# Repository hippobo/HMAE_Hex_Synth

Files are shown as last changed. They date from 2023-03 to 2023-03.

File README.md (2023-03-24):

# HMAE_Hex_Synth

Hex Synth project with resistive touch pads based on ekkoflok hex synth project : https://www.ekkoflok.dk/hex.php

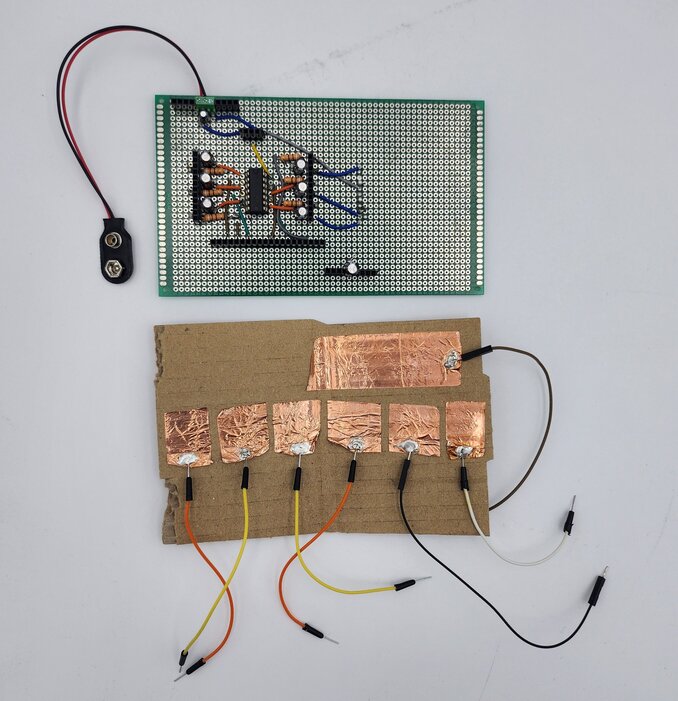
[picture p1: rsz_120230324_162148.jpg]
Prototype

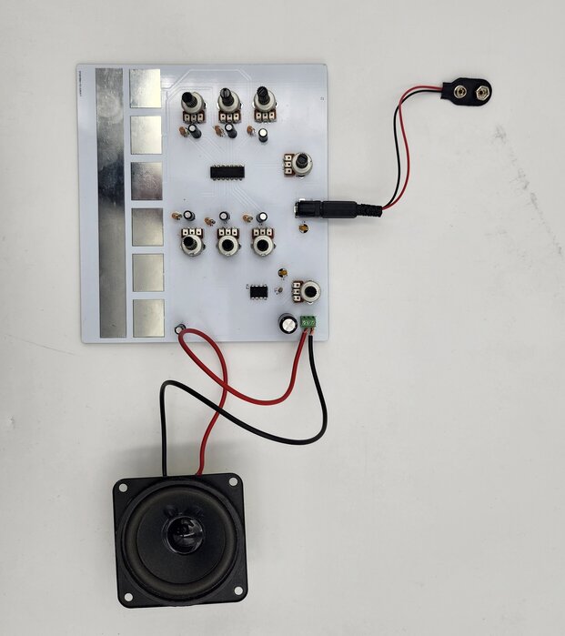
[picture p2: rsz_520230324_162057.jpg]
Final PCB


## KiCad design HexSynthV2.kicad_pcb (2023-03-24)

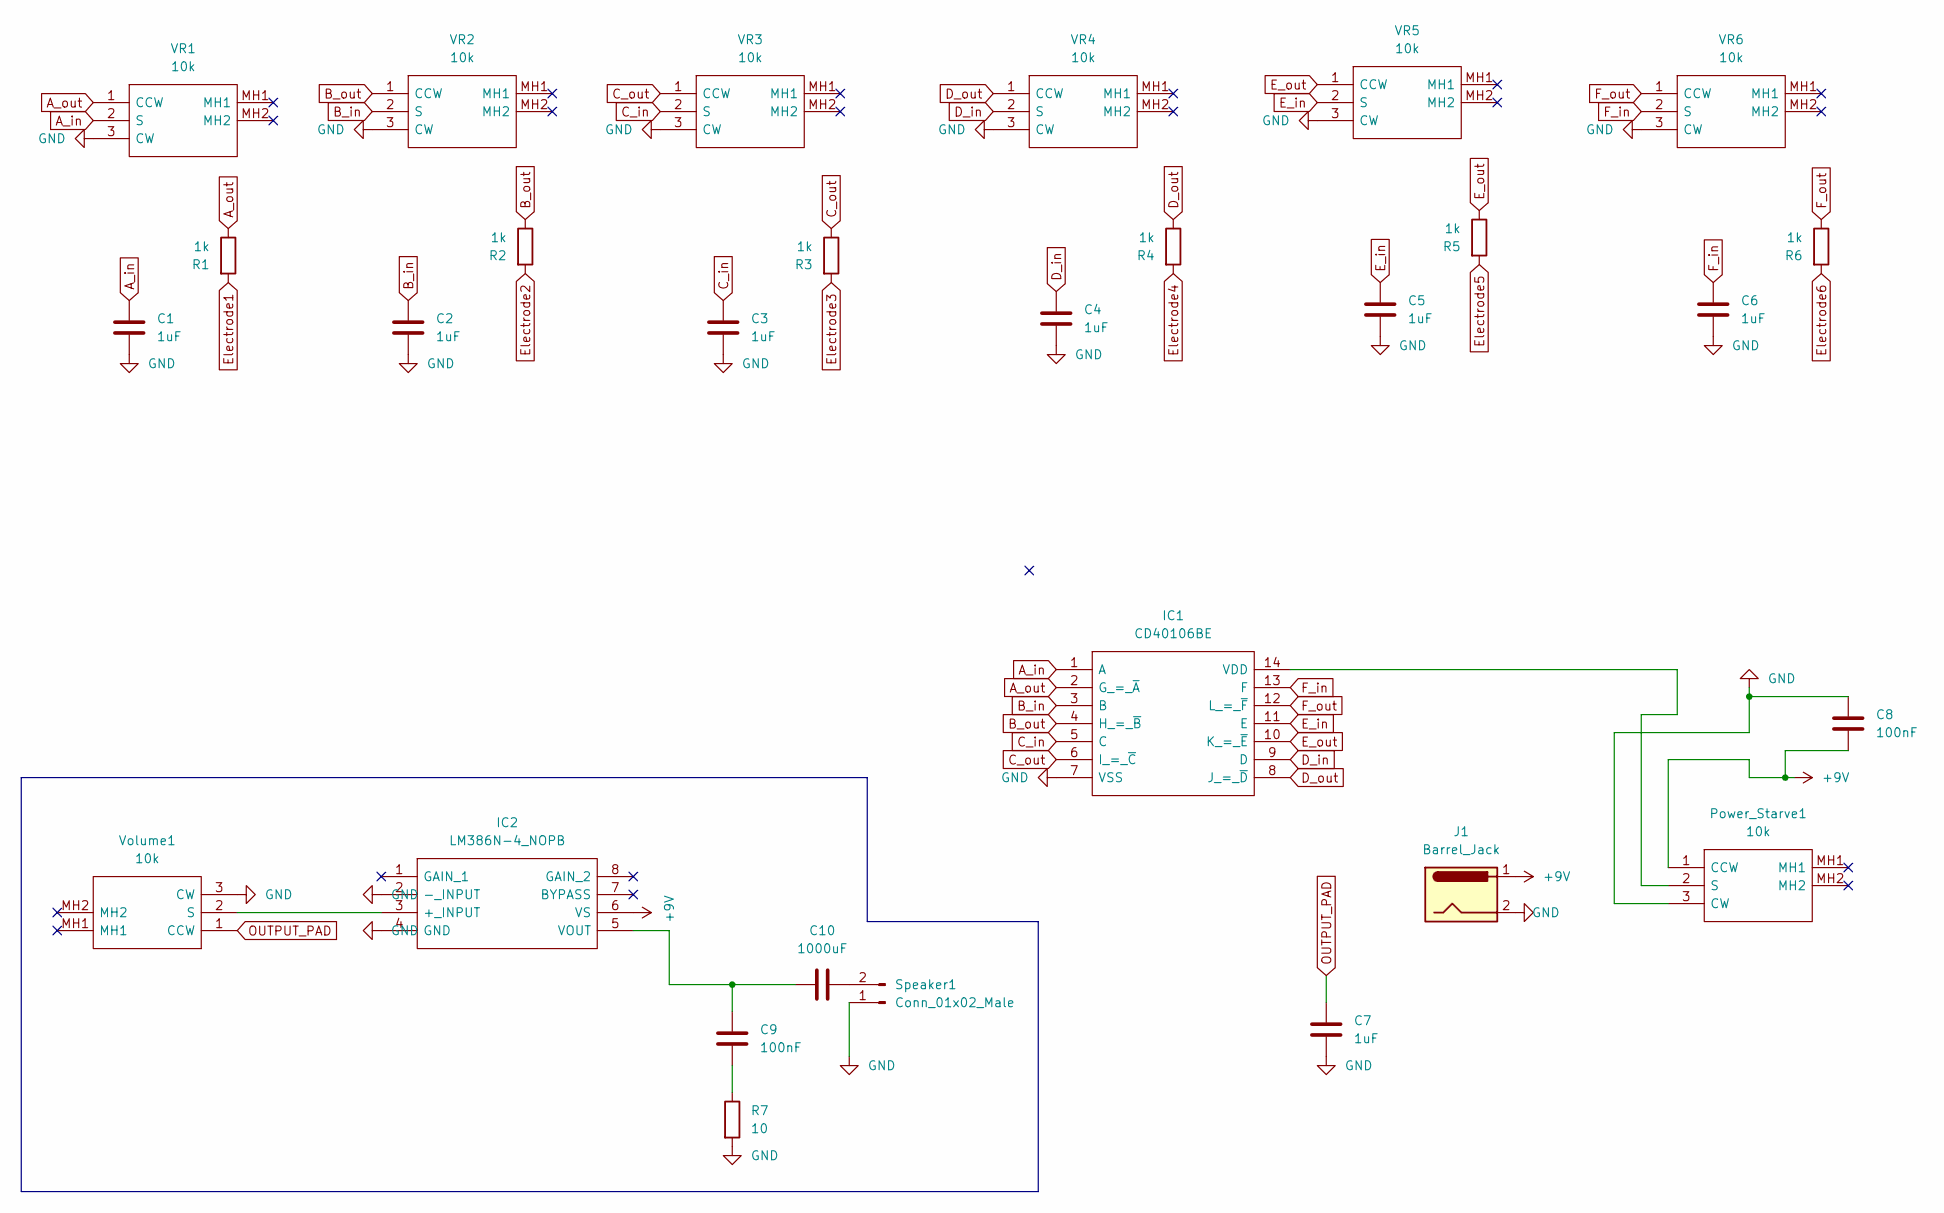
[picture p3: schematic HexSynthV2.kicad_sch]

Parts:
C1, C2, C3, C4, C5, C6, C7: 1uF; CP_Radial_D5.0mm_P2.50mm
C8, C9: 100nF; CP_Radial_D5.0mm_P2.50mm
C10: 1000uF; CP_Radial_D8.0mm_P5.00mm
IC1: CD40106BE; DIP794W53P254L1930H508Q14N; Mouser Part Number 595-CD40106BE
IC2: LM386N-4_NOPB; DIP794W53P254L959H508Q8N; Mouser Part Number 926-LM386N-4/NOPB
J1: Barrel_Jack; BarrelJack_Horizontal
Power_Starve1: 10k; P120PKY25BR10K; Mouser Part Number 858-P120PKY25BR10K
R1, R2, R3, R4, R5, R6: 1k; R_Axial_DIN0204_L3.6mm_D1.6mm_P2.54mm_Vertical
R7: 10; R_Axial_DIN0204_L3.6mm_D1.6mm_P2.54mm_Vertical
Speaker1: Conn_01x02_Male; PinHeader_1x02_P2.54mm_Vertical
VR1, VR2, VR3, VR4, VR5, VR6: 10k; P120PKY25BR10K; Mouser Part Number 858-P120PKY25BR10K
Volume1: 10k; P120PKY25BR10K; Mouser Part Number 858-P120PKY25BR10K

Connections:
+9V: C8.1, IC2.6 (VS), J1.1, Power_Starve1.1 (CCW)
A_in: C1.1, IC1.1 (A), VR1.2 (S)
A_out: IC1.2 (G_=_~A), R1.1, VR1.1 (CCW)
B_in: C2.1, IC1.3 (B), VR2.2 (S)
B_out: IC1.4 (H_=_~B), R2.1, VR2.1 (CCW)
C_in: C3.1, IC1.5 (C), VR3.2 (S)
C_out: IC1.6 (I_=_~C), R3.1, VR3.1 (CCW)
D_in: C4.1, IC1.9 (D), VR4.2 (S)
D_out: IC1.8 (J_=_~D), R4.1, VR4.1 (CCW)
E_in: C5.1, IC1.11 (E), VR5.2 (S)
E_out: IC1.10 (K_=_~E), R5.1, VR5.1 (CCW)
Electrode1: R1.2
Electrode2: R2.2
Electrode3: R3.2
Electrode4: R4.2
Electrode5: R5.2
Electrode6: R6.2
F_in: C6.1, IC1.13 (F), VR6.2 (S)
F_out: IC1.12 (L_=_~F), R6.1, VR6.1 (CCW)
GND: C1.2, C2.2, C3.2, C4.2, C5.2, C6.2, C7.2, C8.2, IC1.7 (VSS), IC2.2 (-_INPUT), IC2.4 (GND), J1.2, Power_Starve1.3 (CW), R7.2, Speaker1.1, VR1.3 (CW), VR2.3 (CW), VR3.3 (CW), VR4.3 (CW), VR5.3 (CW), VR6.3 (CW), Volume1.3 (CW)
unnamed: C9.1, R7.1
unnamed: C9.2, C10.1, IC2.5 (VOUT)
unnamed: C10.2, Speaker1.2
unnamed: IC1.14 (VDD), Power_Starve1.2 (S)
unnamed: IC2.3 (+_INPUT), Volume1.2 (S)
OUTPUT_PAD: C7.1, Volume1.1 (CCW)

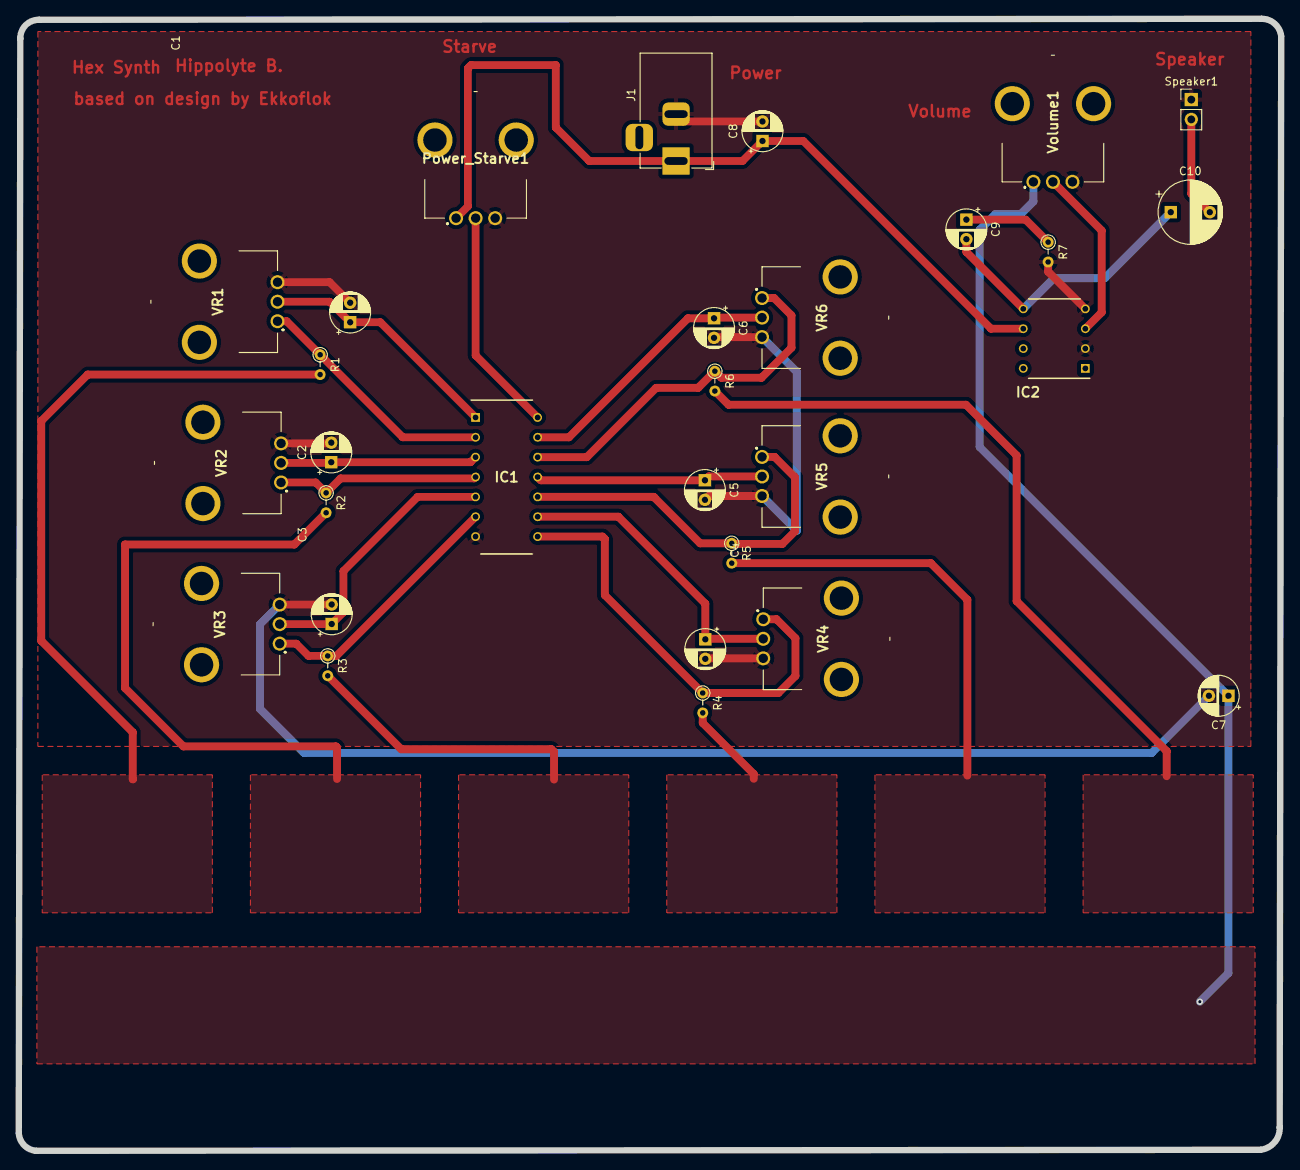
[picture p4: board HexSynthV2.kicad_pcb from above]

Board: 2 copper layers, 161.5 x 144.8 mm, 29 parts (0 on the bottom side), 20 nets.
